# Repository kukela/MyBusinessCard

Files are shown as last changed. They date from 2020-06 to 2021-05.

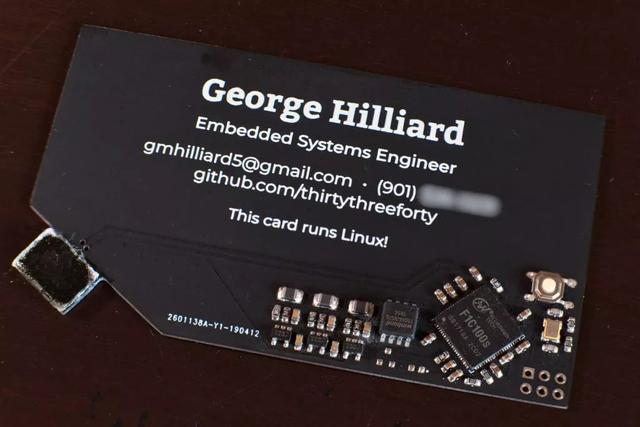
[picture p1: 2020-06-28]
doc/b3119313b07eca8072476fcf4dd486dba0448351.jpeg

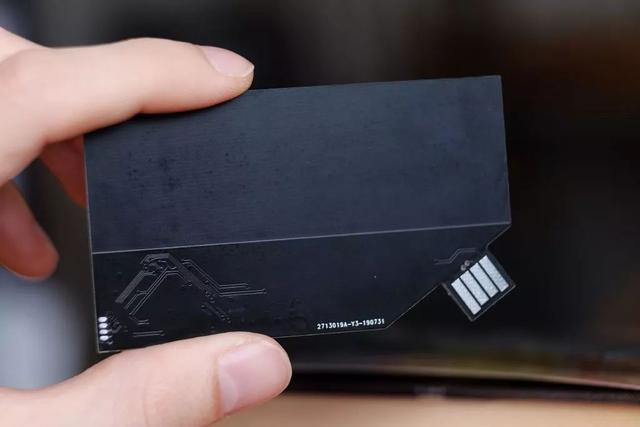
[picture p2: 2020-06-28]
doc/908fa0ec08fa513de781dd27e69a44fdb3fbd91a.jpeg

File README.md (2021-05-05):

### 1. 介绍
#### 1.1. 功能介绍
当手机连接上名片Wi-Fi后会打开个人网站。<br>
进入/admin页面后可以设置Wi-Fi、升级固件、更新网站、配置设备、文件管理。<br>
名片上有两个LED灯可以通过Http协议操作。<br>

#### 1.2. 硬件介绍
原理图和PCB开源地址（右键工程切换版本） -> <a href="https://oshwhub.com/kukela/mybusinesscard" target="_blank">最新版链接</a><br>
USB即插即用。<br>
PCB去嘉立创打样5块钱5个，ESP8266EX在淘宝4块钱就能买到，名片物料成本在10块钱左右。<br>
外观参考了国外大神 George Hilliard 的设计。<br>

#### 1.3. 视频
<a href="https://www.bilibili.com/video/BV18K411P7Zs/" target="_blank">项目介绍</a>、<a href="https://www.bilibili.com/video/BV1G54y11733/" target="_blank">功能演示 性能测试 制作过程</a>、<a href="https://www.bilibili.com/video/BV1wK4y1Y7S2/" target="_blank">心得体会</a><br>
<a href="https://www.youtube.com/watch?v=RA2ZFGR8FDk" target="_blank">YouTube</a><br>
教程：<a href="https://www.bilibili.com/video/BV1ay4y1C7zS/" target="_blank">PCB天线阻抗匹配实用教程</a>、<a href="https://www.youtube.com/watch?v=T8HaHW5-5hg&list=PLIE3qVbtOw1usafOfu7ap5RvYLhmlWPla" target="_blank">YouTube</a>

#### 1.4. 图片展示
<br>
<br>
<br>

#### 1.5. 硬件版本介绍

| 序号/版本 | 日期 | 说明 |
| --- | --- | --- |
| 1 / 1 | 2020-9-19 | 实现基础功能 |
| 2 / 2 | 2020-9-30 | SPI升级为4线读写，晶振升级为40MHz |
| 3 / 2.1  | 2020-5-5  | 稳定性和装配优化，烧录通信接口改成触点式； |

#### 1.6. 推荐配置
##### 1.6.1. 硬件
最新PCB版本<br>
W25Q系列SPI Flash（根据所需选择大小，越大速度越慢，推荐8MB，云上的固件是16MB的）<br>

##### 1.6.2 烧录
CPU Frequency: 160 MHz<br>
Crystal Frequency: 40 MHz<br>
Flash Size: 根据硬件选择<br>
Flash Mode: QIO —— 4线读写<br>
Flash Frequency: 80 MHz<br>
lwIP Variant: v2 Higher Bandwidth (no features)  —— 高带宽（少占用Flash空间）<br>
其余默认<br>

### 2. 开发工具
1. 嵌入式IDE：Arduino（硬件程序开发）<br>
2. EDA工具：立创EDA（原理图和PCB设计）<br>
<br>
3. 电磁仿真：Ansys HFSS（天线阻抗匹配）仿真文件需用ANSYS Electronics Desktop打开<br>
<br>
<br>
4. 3D建模：SketchUP（USB小零件）<br>
<br>
5. Admin页面：使用了HbuilderX开发，NPM，Gulp打包。在命令行输入`gulp`可以把admin页面编译到build/admin.html里面，并且压缩成一行。<br>
6. 文件存储服务：升级更新相关文件存放在阿里云oss<br>
<br>
7. 工具：打包spiffs工具在tool目录里面<br>

### 3. 准备
1. 建议去淘宝买一个ESP LINK，可以很方便的调试。<br>
<br>

### 4. 注意
1. ESP LINK 的 RXD接RXD，TXD接TXD，GND需要和名片的GND共地。接口不支持热插拔！！
2. 烧录前保证线路连接正常，然后断掉总电源在接上。如果Arduino报错，建议关掉再打开，或者重启电脑。
3. PCB厚度1.0mm。
4. ESP8266EX最大支持16MB Flash，可用Web主页空间不到15MB。
5. 个人网站文件名称包括路径长度不能超过31字节，建议使用vue-cli或webpack开发。

### 5. 性能测试
#### 5.1. 烧录配置表

| 测试序号头 | CPU频率 | 晶振频率 | Flash模式 | Flash频率 | lwIP Variant |
| --- | --- | --- | --- | --- | --- |
| A | 80MHz | 26MHz | DOUT | 40MHz | 低内存 |
| B | 160MHz | 26MHz | DOUT | 80MHz | 低内存 |
| CA | 160MHz | 26MHz | DIO | 80MHz | 高带宽 |
| CB | 160MHz | 26MHz | QIO | 80MHz | 高带宽 |
| CC | 160MHz | 40MHz | QIO | 80MHz | 高带宽 |

#### 5.1. 测试参数表

| 测试序号 | 测试软件版本 | 硬件 | Flash大小 |  测试时间  | 测试手机 |
| --- | --- | --- | --- | --- | --- |
| A1 | 2020-9-18 | ESP12-F开发板 | 4MB | 2020-9-18 | 荣耀30 |
| A2 | 2020-9-18 | 1 | 8MB | 2020-9-18 | 荣耀30 |
| B1 | 2020-9-29 | ESP12-F开发板 | 4MB | 2020-9-29 | 荣耀30 |
| B2 | 2020-9-29 | ESP-01S | 2MB | 2020-9-29 | 荣耀30 |
| B3 | 2020-9-29 | 1 | 2MB | 2020-9-29 | 荣耀30 |
| B4 | 2020-9-29 | 1 | 16MB | 2020-9-29 | 荣耀30 |
| CA | 2020-9-29 | 1 | 16MB | 2020-9-30 | 荣耀30 |
| CB1 | 2020-9-29 | ESP-01S | 2MB | 2020-9-30 | 荣耀30 |
| CB2 | 2020-9-29 | ESP-01S | 16MB | 2020-9-30 | 荣耀30 |
| CB3 | 2020-9-29 | 2 | 16MB | 2020-9-30 | 荣耀30 |
| CC | 2020-9-29 | 2 | 16MB | 2020-9-30 | 荣耀30 |

#### 5.2. 测试速度表

| 测试序号 | 近程(ms) | 近程平均(ms) | 远程(ms) | 远程平均(ms) |
| --- | --- | --- | --- | --- |
| A1 | 1446,1206,1320,1254,990  | 1243.2 | 2261,1631,1656,2063,1785 | 1879.2 |
| A2 | 1549,1434,1171,1368,1193 | 1343 | 2827,1633,1703,1507,1479 | 1829.8 |
| B1 | 1550,1750,1669,1033,1249 | 1450.2 | 8889,7086,6086,1703,3103 | 5373.4 |
| B2 | 1776,1816,1727,1093,1199 | 1522.2 | 1871,1758,1690,1352,1330 | 1600.2 |
| B3 | 1685,1547,1600,1131,1023 | 1397.2 | 2466,2102,2114,1372,1398 | 1890.4 |
| B4 | 1714,1587,1880,1455,1578 | 1642.8 | 2097,2015,2018,1625,1620 | 1875 |
| CA | 1174,1109,1298,734,852 | 1033.4 | 1384,1330,1439,1185,948  | 1257.2 |
| CB1 | 1018,983,1096,524,592 | 842.6 | 1682,1325,1475,918,720 | 1224 |
| CB2 | 1266,1215,1162,739,764 | 1029.2 | 1606,1554,1682,930,1205  | 1395.4 |
| CB3 | 1201,1014,1048,886,974 | 1024.6 | 1293,1240,1268,961,864 | 1125.2 |
| CC | 1119,1152,1128,818,748 | 993 | 1310,1148,1200,771,793 | 1044.4 |

#### 5.3. 说明
一般情况下，SPI Flash越小，频率越快，测试速度就越快，当然也可能越不稳定。<br>
由于测试受到手机服务请求、天线射频方向、环境等因素影响，所以以上数据仅供参考。<br>
测试都是在关闭缓存下完成。<br>

##### 5.3.1. A开头的测试
测的是加载到js代码后，网页全部加载完毕的速度。<br>
第1次测的是第一次连接的速度，其余4次测的是在连接情况下，再打开的速度。<br>
尽量保持角度、距离、高度相同进行测试。<br>
近程指距离20厘米之内，远程指距离4米左右，并且隔两堵墙。<br>

##### 5.3.2. B、C开头
测的是图片加载完毕速度。<br>
前3次测的是第一次连接的速度，其余2次测的是浏览器加载完毕刷新的速度。<br>
从芯片到天线的方向为正，正对着手机并且高度误差在10cm内进行测试。<br>
近程指距离30厘米之内，远程指距离4米左右，并且隔两堵墙。<br>

#### 5.4. 结论
在近程情况下，速度受到lwIP Variant、Flash大小、Flash模式（上传）影响较大，CPU、晶振、Flash频率其次。<br>

<br>

****

<br>

你的支持，是我不断贡献的动力！<br>


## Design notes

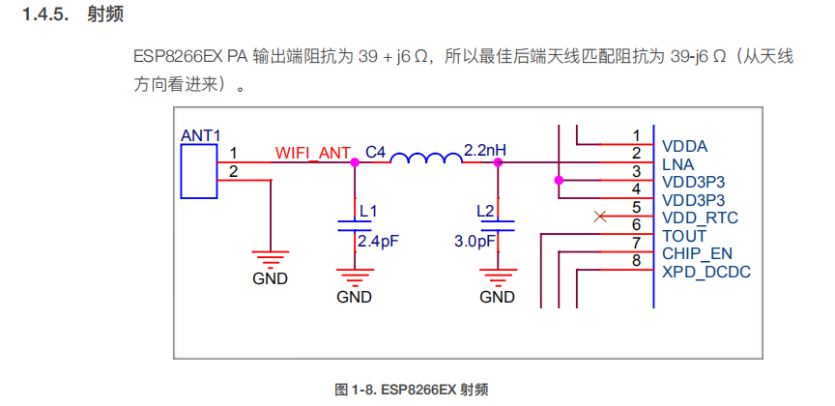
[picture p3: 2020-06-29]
doc/ESP8266硬件设计指南/射频.png

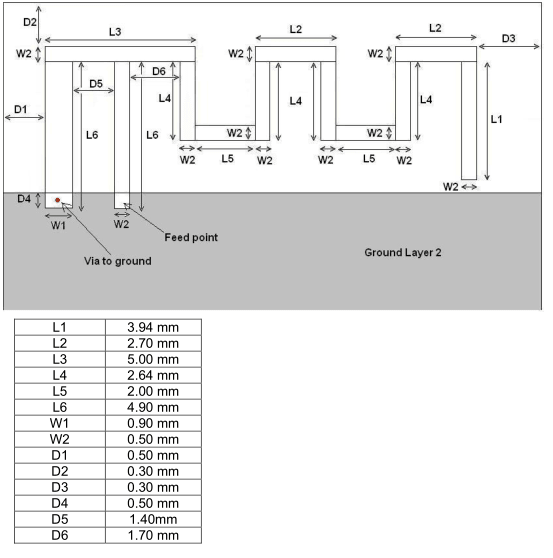
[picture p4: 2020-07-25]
doc/ant.png

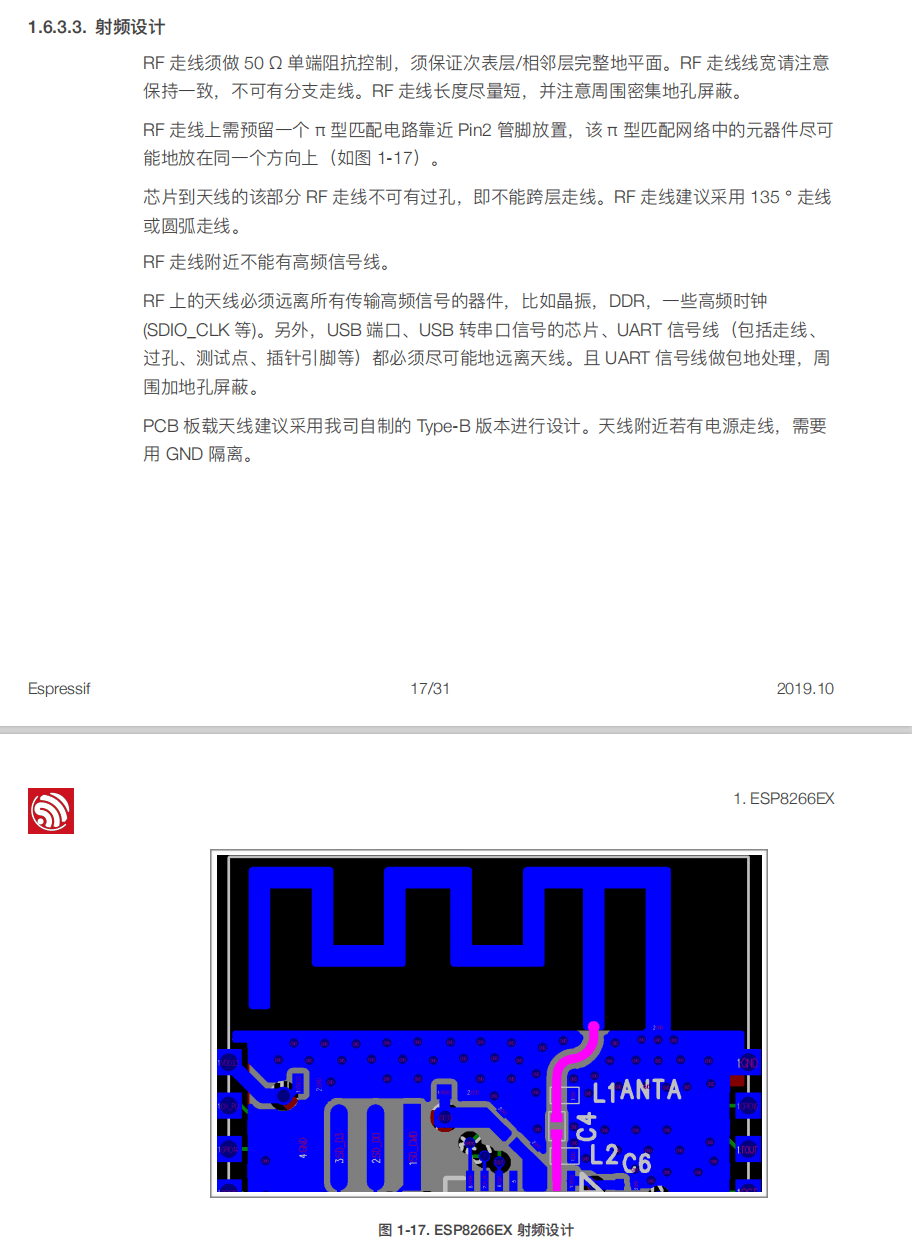
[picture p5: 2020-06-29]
doc/ESP8266硬件设计指南/射频设计.png

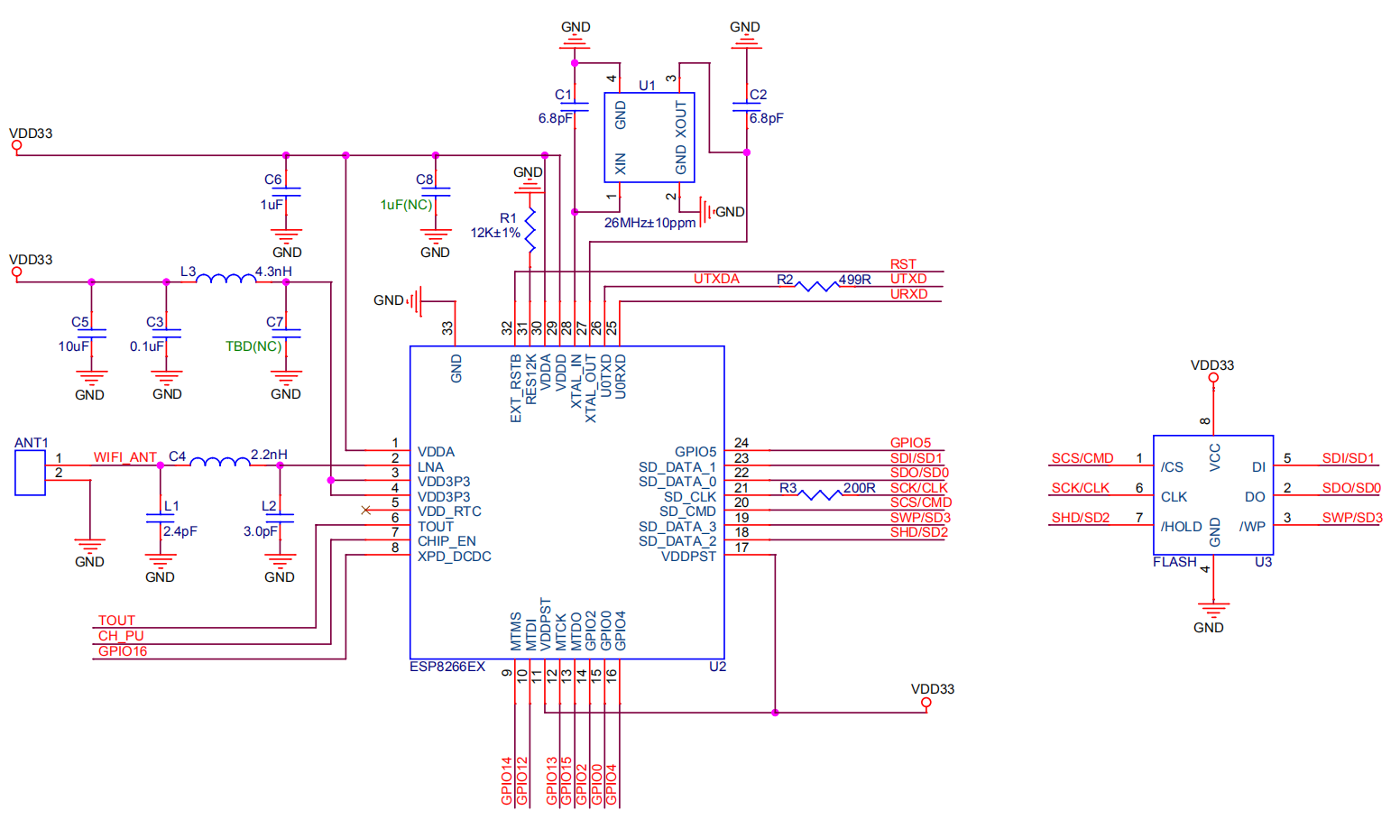
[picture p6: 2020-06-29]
doc/ESP8266硬件设计指南/核心电路.png

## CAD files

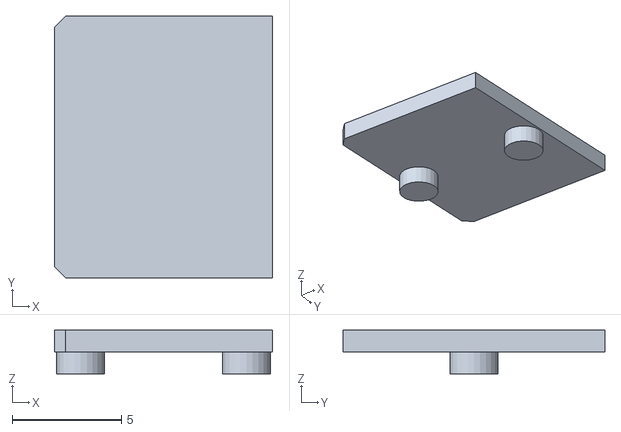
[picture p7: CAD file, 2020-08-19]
release/obj/b.stl
10.0 x 12.0 x 2.00

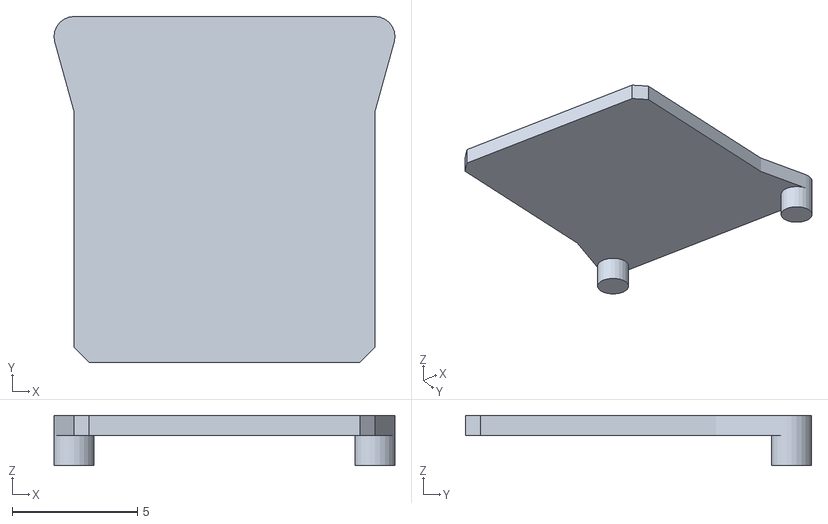
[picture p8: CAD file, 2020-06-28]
release/obj/a.stl
13.6 x 13.8 x 2.00

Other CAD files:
skp/a.skp
skp/b.skp

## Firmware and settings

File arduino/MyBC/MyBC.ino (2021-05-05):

#include <ESP8266WiFi.h>
#include <DNSServer.h>
#include <ESP8266mDNS.h>
#include <ESP8266WebServer.h>
#include <ESP8266httpUpdate.h>
#include <FS.h>
#include <Ticker.h>
#include <EEPROM.h>
#include "config.h"

void setup()
{
  Serial.begin(115200);
  EEPROM.begin(eepromSize);

  while (!Serial)
    ;
  Serial.println();

  pinMode(L1, OUTPUT);
  pinMode(L2, OUTPUT);

  WiFi.mode(WIFI_AP);
  WiFi.softAPConfig(apIP, apIP, IPAddress(255, 255, 255, 0));
  setChangeAP();

  dnsServer.setErrorReplyCode(DNSReplyCode::NoError);
  dnsServer.start(DNS_PORT, "*", apIP);

  webServer.on("/", handleRoot);
  webServer.on("/generate_204", handleRoot);
  webServer.on("/fwlink", handleRoot);
  webServer.on("/wifi", handleWifi);
  webServer.on("/wifisave", handleWifiSave);
  webServer.onNotFound(handleNotFound);
  webServer.on("/admin", handleAdmin);
  webServer.on("/info", HTTP_GET, handleGetFSInfo); // 文件信息
  webServer.on("/update", HTTP_POST, handleFileUploadAfter, handleFileUpload); // 上传文件
  webServer.on("/is", HTTP_GET, handleIS); // 指令集
  webServer.on("/led", HTTP_GET, handleLed); // led操作
  webServer.on("/config", HTTP_GET, handleConfig); // 配置信息
  webServer.on("/putConfig", HTTP_GET, handlePutConfig); // 设置配置
  webServer.on("/wifiscan", HTTP_GET, handleWifiscan); // 返回 Wi-Fi 扫描结果
  webServer.on("/wificonn", HTTP_GET, handleWificonn); // 连接 Wi-Fi
  webServer.on("/wificonf", HTTP_GET, handleWificonf); // 返回 Wi-Fi 配置
  webServer.on("/version", HTTP_GET, handleVersion); // 返回版本
  webServer.on("/nVersion", HTTP_GET, handleNVersion); // 返回最新版本
  webServer.on("/update", HTTP_GET, handleUpdate); // 升级
  webServer.on("/progress", HTTP_GET, handleProgress); //获取进度
  webServer.begin();

  if (!SPIFFS.begin()) {
    Serial.println("fs begin error");
    return;
  }

  getEEPROM();
  connect = strlen(ssid) > 0;

  ledLight(1);
  ticker.once_ms(1000, offLed);
}

void loop()
{
  if (connect) {
    Serial.println("Connect requested");
    connect = false;
    connectWifi();
    lastConnectTry = millis();
  }
  {
    unsigned int s = WiFi.status();
    if (s == 0 && millis() > (lastConnectTry + 60000)) {
      connect = true;
    }
    if (status != s) { // WLAN status change
      Serial.print("Status: ");
      Serial.println(s);
      status = s;
      if (s == WL_CONNECTED) {
        Serial.println("Wi-Fi connection successful");
        Serial.print("IP address: ");
        Serial.println(WiFi.localIP());
        // Setup MDNS responder
        if (!MDNS.begin(myHostname)) {
          Serial.println("Error setting up MDNS responder!");
        } else {
          Serial.println("mDNS responder started");
          // Add service to MDNS-SD
          MDNS.addService("http", "tcp", 80);
        }
      } else if (s == WL_NO_SSID_AVAIL) {
        WiFi.disconnect();
      }
    }
    if (s == WL_CONNECTED) {
      MDNS.update();
    }
  }

  dnsServer.processNextRequest();
  webServer.handleClient();
}

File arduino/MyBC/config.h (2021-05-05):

// 硬件版本序号，详情请看README.md中的1.5章节
#define HV_N 3

// 引脚地址
#define L1 4
#define L2 5

// 网络相关
static String MSSID = "aMyCard";
static String MPSK = "";
IPAddress apIP(192, 168, 1, 1);
DNSServer dnsServer;
static const byte DNS_PORT = 53;
ESP8266WebServer webServer(80);
const char *myHostname = "hello";
WiFiClient client;

// Wi-Fi相关
char ssid[33] = "";
char password[65] = "";
bool connect = false;
unsigned long lastConnectTry = 0;
unsigned int status = WL_IDLE_STATUS;

// 网页相关
static const char TEXT_PLAIN[] PROGMEM = "text/plain;charset=UTF-8";
static const char APP_JSON[] PROGMEM = "application/json";
static const char adminHTML[] PROGMEM = "<!DOCTYPE html><html><head><meta charset='utf-8'><meta name='viewport' content='width=device-width,initial-scale=1,minimum-scale=1,maximum-scale=1,user-scalable=no'><title>admin</title><style>body{padding:0;max-width:800px;margin:0 auto;color:#303133}.jj{margin:0 20px}.t1{position:relative;height:60px;margin-top:20px}.t1,.t2{display:flex;align-items:center}.t1:first-of-type{margin-top:0}.t1 h1{margin:0;flex:1;color:#303133}.t2{min-height:30px;margin-top:10px}.t2.c{min-height:50px}.t2>.t{font-size:16px;line-height:24px;color:#303133;flex:1}.t2>input{width:44px}.dc{height:44px;line-height:44px;border-radius:4px;padding:0 12px;color:#303133;font-size:16px;background:#ebeef5;border:1px solid #e4e7ed}.dc.pt1{margin-top:20px}.rbtn{margin-left:10px;min-width:78px}.dc:hover:not([disabled]){background:#e4e7ed;border-color:#ccc;text-decoration:none}button[disabled],label[disabled],select[disabled]{color:#909399}.rl{overflow:hidden;text-decoration:none;cursor:pointer;display:block}input[type=file]{position:absolute;width:0;opacity:0;display:inline-block}.item{position:relative;display:flex;min-height:30px;margin:10px 20px 0 20px}.item.v{flex-direction:column}.item>div{font-size:14px;color:#303133;line-height:30px}.item>input,.item>select{flex:1}.item .info{font-size:14px;color:#606266;line-height:22px}table{width:100%;border-collapse:collapse}#state,td{font-size:14px;color:#303133;line-height:28px}thead td{font-weight:700}tr td:first-letter{padding-left:20px}tr td:last-child{padding-left:20px}table .drak{background-color:#ebeef5}#state{margin:20px;display:none}</style></head><body><div class='t1 jj'><h1>Wi-Fi 设置</h1></div><div class='t2 jj'><div class='t'>Wi-Fi 名称</div></div><div class='item'><select id='ssid' class='dc' onchange='WCBtnReset()'></select><button id='scan' class='dc rbtn' onclick='reqScanSsid()'>刷 新</button></div><div class='t2 jj'><div class='t'>Wi-Fi 密码</div></div><div class='item'><input id='pwd' class='dc' type='password' placeholder='请输入 Wi-Fi 密码' value='' onchange='WCBtnReset()'></div><div class='item v'><div class='info'>当设备在同一局域网内，可以通过 <a href='http://hello.local'>hello.local</a> 访问（安卓手机不支持），或者内网IP地址 <a id='hip'></a> 访问，效果和直接连名片Wi-Fi是一样的。</div><button id='wificonn' class='dc pt1' onclick='reqConnSsid()'></button></div><div class='t1 jj'><h1>更新</h1></div><div class='t2 c jj'><div id='ver' class='t'></div><button id='vup' class='dc rbtn' onclick='reqUpdate(0)'></button></div><div class='t2 c jj'><div id='wver' class='t'></div><button id='wup' class='dc rbtn' onclick='reqUpdate(1)'></button></div><div class='item v'><div class='info'>不推荐在直连名片Wi-Fi的情况下升级固件，因为升级过程会导致Wi-Fi断开，从而不能获取升级反馈。</div></div><div class='t1 jj'><h1>配置</h1></div><div class='t2 jj'><div class='t'>选择信道</div></div><div class='item'><select id='channel' class='dc' onchange='cChnage()'><option value='1'>1 ---------- 2.412GHz</option><option value='2'>2 ---------- 2.417Ghz</option><option value='3'>3 ---------- 2.422Ghz</option><option value='4'>4 ---------- 2.427Ghz</option><option value='5'>5 ---------- 2.432Ghz</option><option value='6'>6 ---------- 2.437Ghz</option><option value='7'>7 ---------- 2.442Ghz</option><option value='8'>8 ---------- 2.447Ghz</option><option value='9'>9 ---------- 2.452Ghz</option><option value='10'>10 -------- 2.457Ghz</option><option value='11'>11 -------- 2.462Ghz</option><option value='12'>12 -------- 2.467Ghz</option><option value='13'>13 -------- 2.472Ghz</option><option value='14'>14 -------- 2.484Ghz</option></select></div><div class='t2 c jj'><div class='t'>开启缓存</div><input id='cache' type='checkbox' onchange='caChange()'></div><div class='t2 jj'><div class='t'>首页地址</div></div><div class='item'><input id='homeUrl' class='dc' type='text' placeholder='请输入网站首页地址' value=''> <button class='dc rbtn' onclick='huChange()'>确 定</button></div><div class='item v'><button class='dc pt1' onclick='resetConf()'>重置所有配置</button></div><div class='t1 jj'><h1>文件管理</h1><form id='fileForm' method='POST' action='/update' enctype='multipart/form-data' target='mf'><label id='fdl' class='dc rl' for='file'>覆盖上传</label><input id='file' type='file' name='file' onchange='fileInputChange()' webkitdirectory multiple='multiple'></form><iframe id='mf' name='mf' style='display:none'></iframe></div><div id='state'></div><div class='item'><div>总容量：<span id='cap'></span>；已用：<span
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

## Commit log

2020-06-29 更新文档
    [05_BOM_ESP_WROOM_02_BOM.xlsx]
2020-07-25 增加测速
2020-08-19 增加选择信道
    [b.skp, b.stl]
2020-08-28 admin页面增加信道选择
2020-09-10 优化代码结构，修复bug，增加配置网站首页
2020-09-13 修复bug增加缓存配置
2020-09-15 增加Wi-FI、固件升级、网站升级功能
2020-09-15 修复bug文档更新
2020-09-15 个人网站源码和文档更新
2020-09-16 个人网站增加更新按钮
2020-09-18 修复bug
2020-09-19 文档更新
2020-09-22 代码优化
2020-09-24 更新文档和开源协议，删除不需要文件
2020-09-29 测速代码修改，测试文档更新
2020-09-29 增加重启提示
2020-09-30 修复bug，硬件更新
2020-10-17 添加视频教程，上传仿真文件
2021-05-05 2.1开发板；优化请求
2021-05-05 优化请求
